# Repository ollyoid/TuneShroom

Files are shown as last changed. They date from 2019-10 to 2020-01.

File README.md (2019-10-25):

# 🎵🍄 TuneShroom
An artistic capacitive MIDI USB controller - Just a small project to practice artistic PCB design and embedded programming. Find out more on my [website](https://oliverchild.com/tuneshroom)

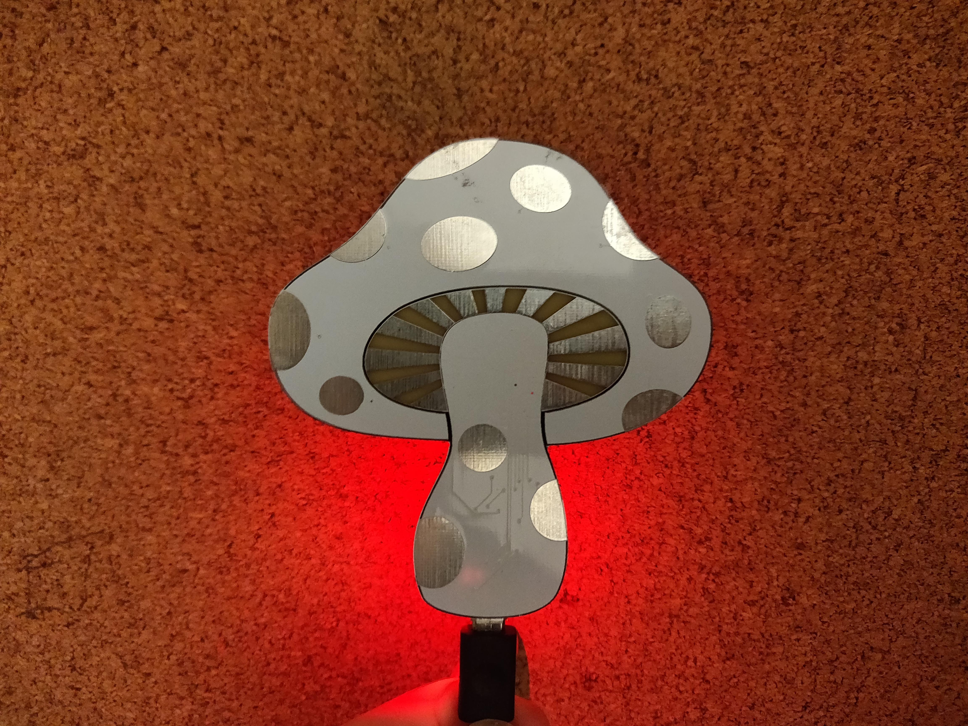
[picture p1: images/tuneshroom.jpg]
tuneshroom


## Hardware
The PCB was designed in KiCAD using the wonderful [svg2shenzhen](https://github.com/badgeek/svg2shenzhen) plugin for Inkscape. The circuit is essentially a [Sparkfun Pro Micro](https://www.sparkfun.com/products/12640), thanks Sparkfun for sharing the schematic! It uses an Atmega32u4 with native USB. Each of the IO pins is hooked directly to one of the touch pads on the front and acts as MIDI key.

## Firmware
I started out using Arduino but to access more pins and have more control I decided to go the bare metal approach. The current firmware is a patched version of [LUFA](https://github.com/abcminiuser/lufa) which does all the USB stuff for me. 

## Programming

To compile the firmware go into the [project folder](lufa/Projects/Tuneshroom/) and `make all`.

To Flash it onto the board you need an AVR programmer of some kind and to build a little ISP programmer with some pogo pins.

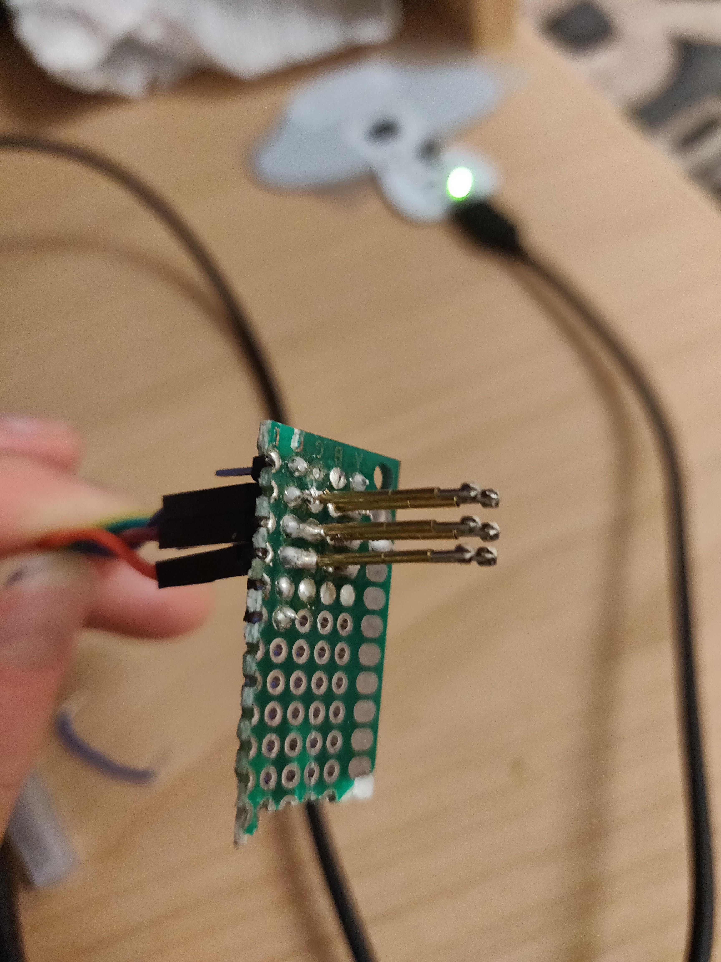
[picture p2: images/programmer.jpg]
programmer


Some fuses have to be changed from their default using:

```avrdude -c usbasp -p ATmega32u4 -U hfuse:w:0xD8:m -U lfuse:w:0xFF:m -U efuse:w:0xCB:```

Then it's just a case of programming it with:

```avrdude -c usbasp -p ATmega32u4 -U flash:w:TuneShroom.hex```

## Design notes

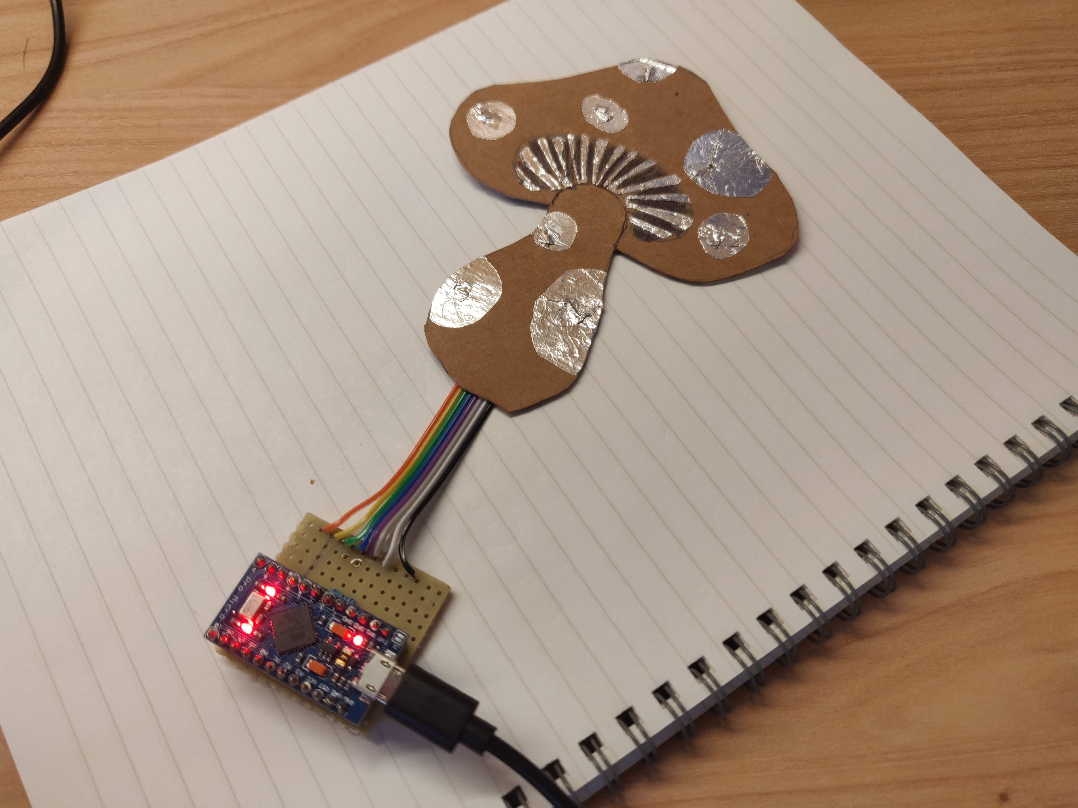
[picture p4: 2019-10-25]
images/prototype.jpg

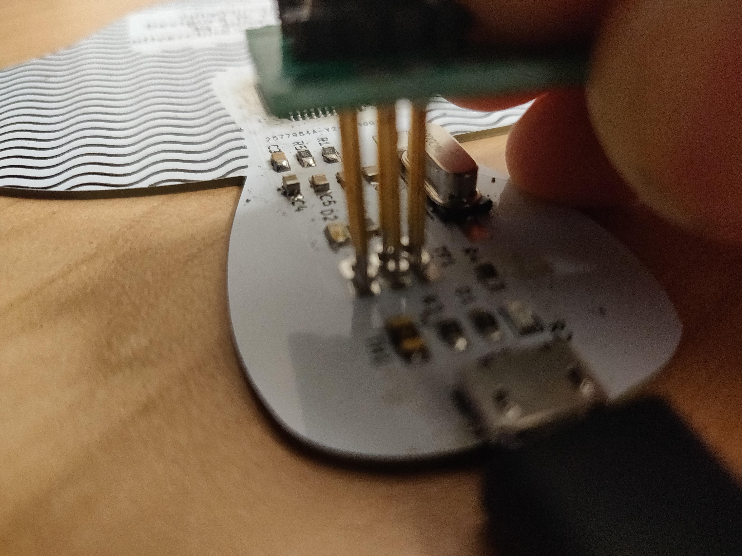
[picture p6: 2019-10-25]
images/programming.jpg

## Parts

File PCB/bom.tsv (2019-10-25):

References | Qty | Description
C1, C2 | 2 | C 22pF Unpolarized capacitor 0805 2012Metric Pad1.15x1.40mm HandSolder
C3, C5 | 2 | C 0.1uF Unpolarized capacitor 0805 2012Metric Pad1.15x1.40mm HandSolder
C4 | 1 | C 1uF Unpolarized capacitor 0805 2012Metric Pad1.15x1.40mm HandSolder
D1, D2 | 2 | LED Light emitting diode 0805 2012Metric Pad1.15x1.40mm HandSolder
J5, J7, J9, J11, J13, J15, J17, J19, J21, J1, J3, J4, J6, J8, J10, J12, J14, J16, J18, J20, J2, J22, J24, J25 | 24 | Conn 01x01 Generic connector, single row, 01x01, script generated (kicad-library-utils/schlib/autogen/connector/) contact
J23 | 1 | USB B Micro Type connector Micro-B Molex 47346-0001
R1, R5 | 2 | R 10K Resistor 0805 2012Metric Pad1.15x1.40mm HandSolder
R2, R3 | 2 | R 22 Resistor 0805 2012Metric Pad1.15x1.40mm HandSolder
R4, R6 | 2 | R 330 Resistor 0805 2012Metric Pad1.15x1.40mm HandSolder
TH1 | 1 | Thermistor Temperature dependent resistor Fuse 1206 3216Metric Pad1.42x1.75mm HandSolder
TP1 | 1 | ICSP
U1 | 1 | ATmega32U4-AU 16MHz, 16kB Flash, 1.25kB SRAM, 512B EEPROM, USB 2.0, TQFP-44 10x10mm P0.8mm
Y1 | 1 | Crystal 16MHz Two pin crystal SMD HC49-SD HandSoldering

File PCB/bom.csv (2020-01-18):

References | Qty | Description | Manufacturer | MPN | Manufacturer | MPN | Manufacturer | MPN | Digikey | Mouser | RS | Newark | Farnell
C1, C2 | 2 | C 22pF 0805 | KEMET | C0805C220J5GACTU | AVX | 08051A220J4T2A |  |  | 399-1113-1-ND | 80C0805C220J5G | 2644258P |  | 1625484
C3, C5 | 2 | C 0.1uF 0805 | Yageo | CC0805KRX7R9BB104 | Murata | GRM21BR71H104KA01L |  |  | 311-1140-6-ND | 603CC805KRX7R9BB104 | 6698842 |  | 3019949
C4 | 1 | C 1uF 0805 | TDK | C2012X7S2A105K125AB | Yageo | CC0805KKX7R8BB105 |  |  | 311-1456-6-ND | 603CC805KKX7R8BB105 | 7883054P |  | 1458903
D1, D2 | 2 | LED 0805 red | Broadcom | HSMS-C170 | VCC | 7012X1 |  |  | 516-1429-6-ND | 630HSMSC170 | 1371306 |  | 5790839
J23 | 1 | USB B Micro Type connector Micro-B Molex 47346-0001 |  | 47346-0001 | Molex | 47346-0001 |  |  | WM17141CT-ND | 538473460001 | 7025475 |  | 1568026
R1, R5 | 2 | R 10K 0805 | Vishay | CRCW080510K0FKEA | Panasonic | ERJ-6ENF1002V | Yageo | RC0805FR-0710KL | 311-10.0KCRDKR-ND | 603RC0805FR0710KL | 6790816 |  | 2148862
R2, R3 | 2 | R 22 0805 | Panasonic | ERJ-6GEYJ220V | Yageo | RC0805JR-0722RL |  |  | 311-22ARCT-ND | 603RC0805JR0722RL | 7326602 |  | 1799493
R4, R6 | 2 | R 330 0805 | Yageo | RC0805FR-07330RL | TE Connectivity | CPF0805B330RE1 |  |  | 311-330CRCT-ND | 603RC0805FR07330RL | 6183195 |  | 9237429
TH1 | 1 | F 1206 0.5A | Bel Fuse | 0ZCJ0050FF2G | Littelfuse | 1206L050YR |  |  | 507-1802-1-ND | 5300ZCJ0050FF2G | 7874198 |  | 2848530
U1 | 1 | ATmega32U4-AU | Microchip | ATMEGA32U4-AUR | Microchip | ATMEGA32U4-AU |  |  | ATMEGA32U4-AURDKR-ND | 556ATMEGA32U4AUR | 1310289 |  | 1748525
Y1 | 1 | Y 16M HC49 | Abracon | ABLS-16.000MHZ-B4-T |  |  |  |  | 535-10226-1-ND | 815ABLS16.0MT | 1710560 |  | 2467721

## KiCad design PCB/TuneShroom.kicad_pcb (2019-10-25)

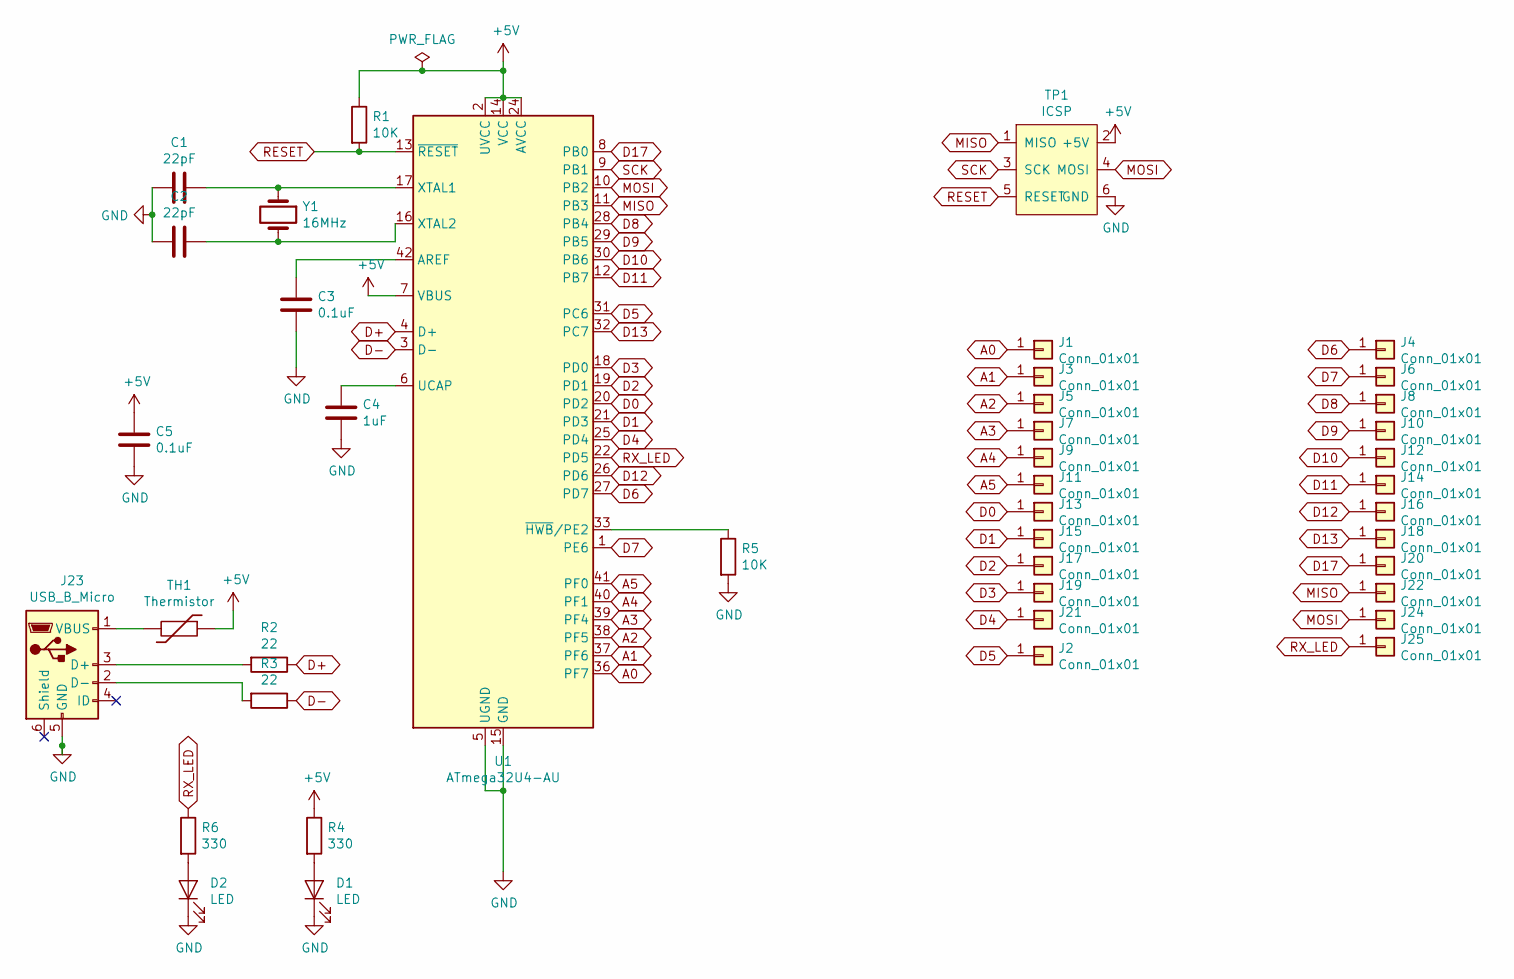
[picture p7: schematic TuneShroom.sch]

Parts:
C1, C2: 22pF; C_0805_2012Metric_Pad1.15x1.40mm_HandSolder
C3, C5: 0.1uF; C_0805_2012Metric_Pad1.15x1.40mm_HandSolder
C4: 1uF; C_0805_2012Metric_Pad1.15x1.40mm_HandSolder
D1, D2: LED; LED_0805_2012Metric_Pad1.15x1.40mm_HandSolder
J1, J2, J3, J4, J5, J6, J7, J8, J9, J10, J11, J12, J13, J14, J15, J16, J17, J18, J19, J20, J21, J22, J24, J25: Conn_01x01; contact
J23: USB_B_Micro; USB_Micro-B_Molex_47346-0001
R1, R5: 10K; R_0805_2012Metric_Pad1.15x1.40mm_HandSolder
R2, R3: 22; R_0805_2012Metric_Pad1.15x1.40mm_HandSolder
R4, R6: 330; R_0805_2012Metric_Pad1.15x1.40mm_HandSolder
TH1: Thermistor; Fuse_1206_3216Metric_Pad1.42x1.75mm_HandSolder
TP1: ICSP
U1: ATmega32U4-AU; TQFP-44_10x10mm_P0.8mm
Y1: 16MHz; Crystal_SMD_HC49-SD_HandSoldering

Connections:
+5V: C5.1, R1.1, R4.1, TH1.1, TP1.2 (+5V), U1.2 (UVCC), U1.7 (VBUS), U1.14 (VCC), U1.24 (AVCC), U1.34 (VCC), U1.44 (AVCC)
A0: J1.1, U1.36 (PF7)
A1: J3.1, U1.37 (PF6)
A2: J5.1, U1.38 (PF5)
A3: J7.1, U1.39 (PF4)
A4: J9.1, U1.40 (PF1)
A5: J11.1, U1.41 (PF0)
D0: J13.1, U1.20 (PD2)
D1: J15.1, U1.21 (PD3)
D2: J17.1, U1.19 (PD1)
D3: J19.1, U1.18 (PD0)
D4: J21.1, U1.25 (PD4)
D5: J2.1, U1.31 (PC6)
D6: J4.1, U1.27 (PD7)
D7: J6.1, U1.1 (PE6)
D8: J8.1, U1.28 (PB4)
D9: J10.1, U1.29 (PB5)
D10: J12.1, U1.30 (PB6)
D11: J14.1, U1.12 (PB7)
D12: J16.1, U1.26 (PD6)
D13: J18.1, U1.32 (PC7)
D17: J20.1, U1.8 (PB0)
D+: R2.1, U1.4 (D+)
D-: R3.1, U1.3 (D-)
GND: C1.2, C2.2, C3.2, C4.2, C5.2, D1.1 (K), D2.1 (K), J23.5 (GND), R5.2, TP1.6 (GND), U1.5 (UGND), U1.15 (GND), U1.23 (GND), U1.35 (GND), U1.43 (GND)
MISO: J22.1, TP1.1 (MISO), U1.11 (PB3)
MOSI: J24.1, TP1.4 (MOSI), U1.10 (PB2)
unnamed: C1.1, U1.17 (XTAL1), Y1.1
unnamed: C2.1, U1.16 (XTAL2), Y1.2
unnamed: C3.1, U1.42 (AREF)
unnamed: C4.1, U1.6 (UCAP)
unnamed: D1.2 (A), R4.2
unnamed: D2.2 (A), R6.2
unnamed: J23.1 (VBUS), TH1.2
unnamed: J23.2 (D-), R3.2
unnamed: J23.3 (D+), R2.2
unnamed: R5.1, U1.33 (~HWB~/PE2)
RESET: R1.2, TP1.5 (RESET), U1.13 (~RESET)
RX_LED: J25.1, R6.1, U1.22 (PD5)
SCK: TP1.3 (SCK), U1.9 (PB1)

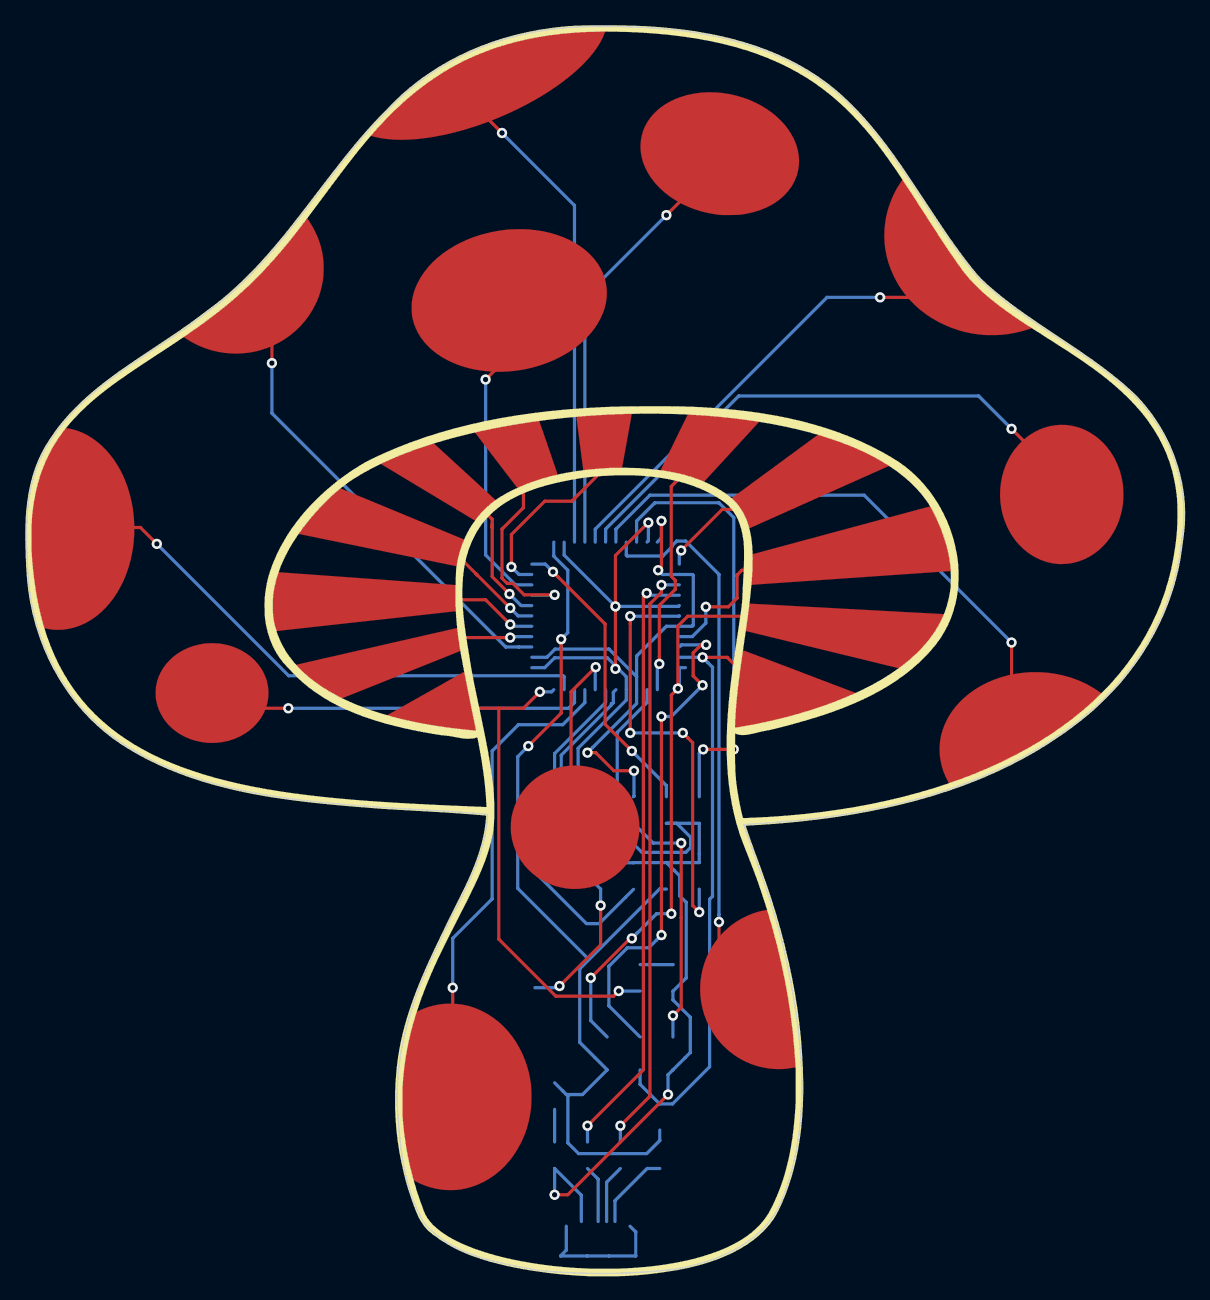
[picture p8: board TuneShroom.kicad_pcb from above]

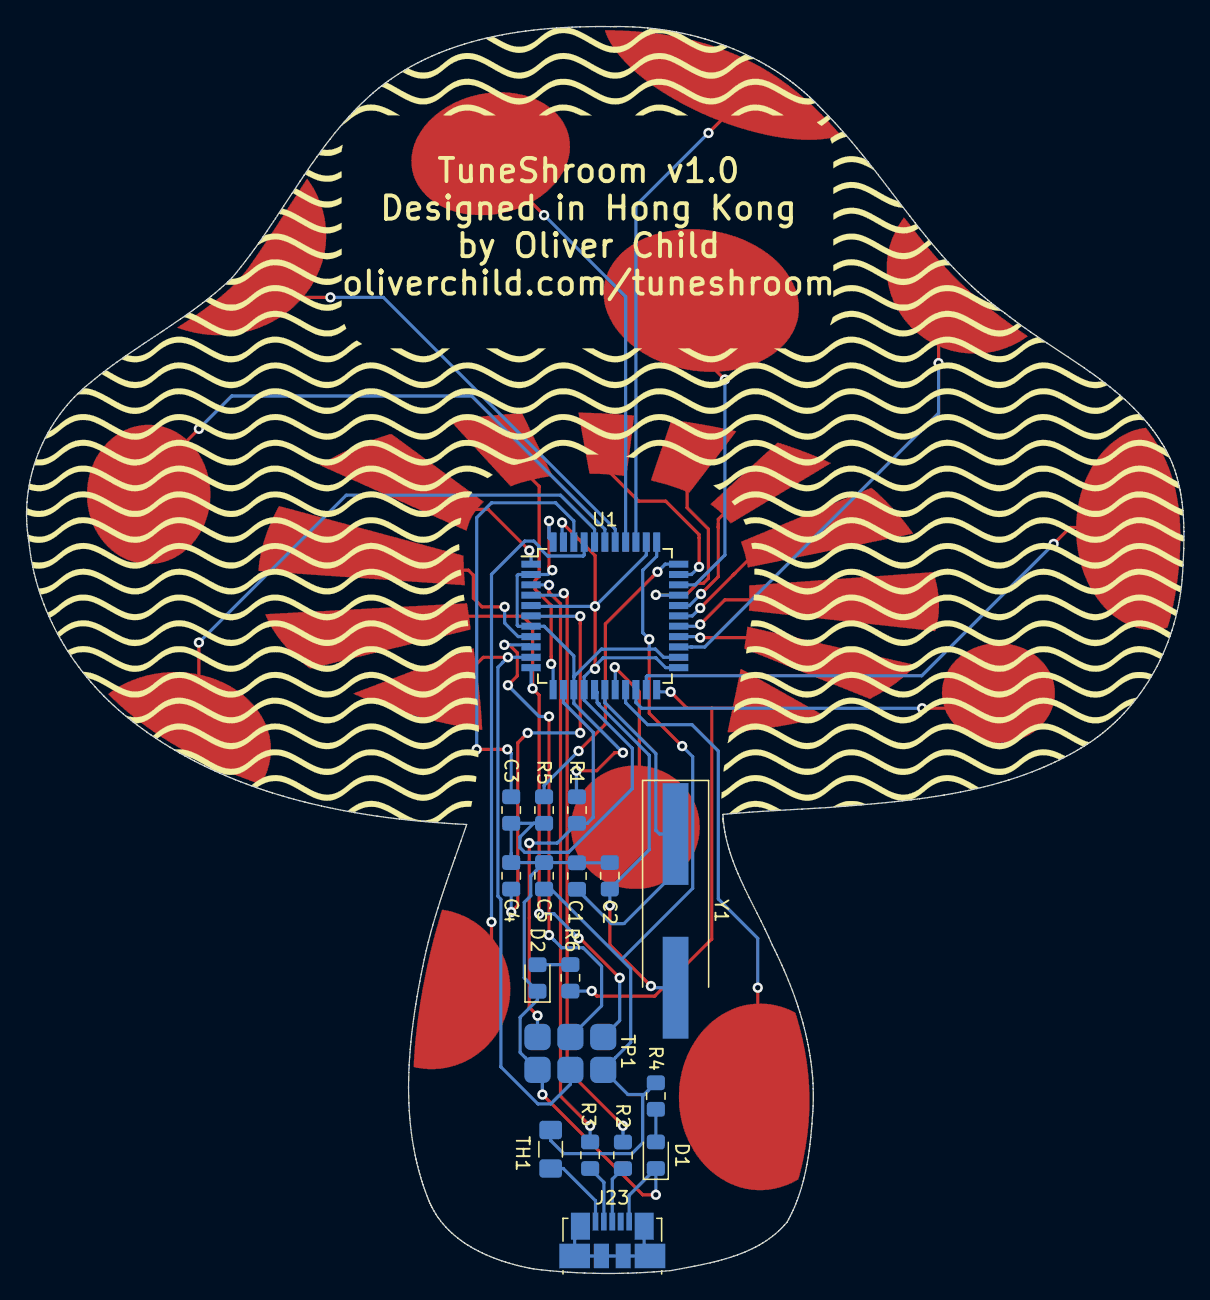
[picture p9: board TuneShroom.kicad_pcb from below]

Board: 2 copper layers, 89.4 x 96.3 mm, 42 parts (18 on the bottom side), 40 nets.

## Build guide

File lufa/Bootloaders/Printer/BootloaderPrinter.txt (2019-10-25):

/** \file
 *
 *  This file contains special DoxyGen information for the generation of the main page and other special
 *  documentation pages. It is not a project source file.
 */

/** \mainpage Printer Class USB AVR Bootloader
 *
 *  \section Sec_Compat Demo Compatibility:
 *
 *  The following list indicates what microcontrollers are compatible with this demo.
 *
 *  \li Series 7 USB AVRs (AT90USBxxx7)
 *  \li Series 6 USB AVRs (AT90USBxxx6)
 *  \li Series 4 USB AVRs (ATMEGAxxU4)
 *  \li Series 2 USB AVRs (AT90USBxx2, ATMEGAxxU2)
 *
 *  \section Sec_Info USB Information:
 *
 *  The following table gives a rundown of the USB utilization of this demo.
 *
 *  <table>
 *   <tr>
 *    <td><b>USB Mode:</b></td>
 *    <td>Device</td>
 *   </tr>
 *   <tr>
 *    <td><b>USB Class:</b></td>
 *    <td>Printer Class</td>
 *   </tr>
 *   <tr>
 *    <td><b>USB Subclass:</b></td>
 *    <td>Printer Subclass</td>
 *   </tr>
 *   <tr>
 *    <td><b>Relevant Standards:</b></td>
 *    <td>USBIF Printer Class Standard</td>
 *   </tr>
 *   <tr>
 *    <td><b>Supported USB Speeds:</b></td>
 *    <td>Full Speed Mode</td>
 *   </tr>
 *  </table>
 *
 *  \section Sec_Description Project Description:
 *
 *  This bootloader enumerates to the host as a Generic Text Only Printer device, capable of reading and parsing
 *  "printed" plain-text Intel HEX files to load firmware onto the AVR.
 *
 *  Out of the box this bootloader builds for the AT90USB1287 with an 8KB bootloader section size, and will fit
 *  into 4KB of bootloader space. If you wish to alter this size and/or change the AVR model, you will need to
 *  edit the MCU, FLASH_SIZE_KB and BOOT_SECTION_SIZE_KB values in the accompanying makefile.
 *
 *  When the bootloader is running, the board's LED(s) will flash at regular intervals to distinguish the
 *  bootloader from the normal user application.
 *
 *  \section Sec_Running Running the Bootloader
 *
 *  On the USB AVR8 devices, setting the \c HWBE device fuse will cause the bootloader to run if the \c HWB pin of
 *  the AVR is grounded when the device is reset.
 *
 *  The are two behaviours of this bootloader, depending on the device's fuses:
 *
 *  <b>If the device's BOOTRST fuse is set</b>, the bootloader will run any time the system is reset from
 *  the external reset pin, unless no valid user application has been loaded. To initiate the bootloader, the
 *  device's external reset pin should be grounded momentarily.
 *
 *  <b>If the device's BOOTRST fuse is not set</b>, the bootloader will run only if initiated via a software
 *  jump, or if the \c HWB pin was low during the last device reset (if the \c HWBE fuse is set).
 *
 *  For board specific exceptions to the above, see below.
 *
 *  \subsection SSec_XPLAIN Atmel Xplain Board
 *  Ground the USB AVR JTAG's \c TCK pin to ground when powering on the board to start the bootloader. This assumes the
 *  \c HWBE fuse is cleared and the \c BOOTRST fuse is set as the HWBE pin is not user accessible on this board.
 *
 *  \subsection SSec_Leonardo Arduino Leonardo Board
 *  Ground \c IO13 when powering the board to start the bootloader. This assumes the \c HWBE fuse is cleared and the
 *  \c BOOTRST fuse is set as the HWBE pin is not user accessible on this board.
 *
 *  \section Sec_Installation Driver Installation
 *
 *  This bootloader uses the Generic Text-Only printer drivers inbuilt into all modern operating systems, thus no
 *  additional drivers need to be supplied for correct operation.
 *
 *  \section Sec_HostApp Host Controller Application
 *
 *  This bootloader is compatible with Notepad under Windows, and the command line \c lpr utility under Linux.
 *
 *  \subsection SSec_Notepad Notepad (Windows)
 *
 *  While most text applications under Windows will be compatible with the bootloader, the inbuilt Notepad utility
 *  is recommended as it will introduce minimal formatting changes to the output stream. To program with Notepad,
 *  open the target HEX file and print it to the Generic Text Only printer device the bootloader creates.
 *
 *  \subsection SSec_LPR LPR (Linux)
 *
 *  While the CUPS framework under Linux will enumerate the bootloader as a Generic Text-Only printer, many
 *  applications will refuse to print to the device due to the lack of rich formatting options available. As a result,
 *  under Linux HEX files must be printed via the low level \c lpr utility instead.
 *
 *  \code
 *  cat Mouse.hex | lpr
 *  \endcode
 *
 *  \section Sec_API User Application API
 *
 *  Several user application functions for FLASH and other special memory area manipulations are exposed by the bootloader,
 *  allowing the user application to call into the bootloader at runtime to read and write FLASH data.
 *
 *  By default, the bootloader API jump table is located 32 bytes from the end of the device's FLASH memory, and follows the
 *  following layout:
 *
 *  \code
 *  #define BOOTLOADER_API_TABLE_SIZE          32
 *  #define BOOTLOADER_API_TABLE_START         ((FLASHEND + 1UL) - BOOTLOADER_API_TABLE_SIZE)
 *  #define BOOTLOADER_API_CALL(Index)         (void*)((BOOTLOADER_API_TABLE_START + (Index * 2)) / 2)
 *
 *  void    (*BootloaderAPI_ErasePage)(uint32_t Address)               = BOOTLOADER_API_CALL(0);
 *  void    (*BootloaderAPI_WritePage)(uint32_t Address)               = BOOTLOADER_API_CALL(1);
 *  void    (*BootloaderAPI_FillWord)(uint32_t Address, uint16_t Word) = BOOTLOADER_API_CALL(2);
 *  uint8_t (*BootloaderAPI_ReadSignature)(uint16_t Address)           = BOOTLOADER_API_CALL(3);
 *  uint8_t (*BootloaderAPI_ReadFuse)(uint16_t Address)                = BOOTLOADER_API_CALL(4);
 *  uint8_t (*BootloaderAPI_ReadLock)(void)                            = BOOTLOADER_API_CALL(5);
 *  void    (*BootloaderAPI_WriteLock)(uint8_t LockBits)               = BOOTLOADER_API_CALL(6);
 *
 *  #define BOOTLOADER_MAGIC_SIGNATURE_START   (BOOTLOADER_API_TABLE_START + (BOOTLOADER_API_TABLE_SIZE - 2))
 *  #define BOOTLOADER_MAGIC_SIGNATURE         0xDCFB
 *
 *  #define BOOTLOADER_CLASS_SIGNATURE_START   (BOOTLOADER_API_TABLE_START + (BOOTLOADER_API_TABLE_SIZE - 4))
 *  #define BOOTLOADER_PRINTER_SIGNATURE       0xDF20
 *
 *  #define BOOTLOADER_ADDRESS_START           (BOOTLOADER_API_TABLE_START + (BOOTLOADER_API_TABLE_SIZE - 8))
 *  #define BOOTLOADER_ADDRESS_LENGTH          4
 *  \endcode
 *
 *  From the application the API support of the bootloader can be detected by reading the FLASH memory bytes located at address
 *  \c BOOTLOADER_MAGIC_SIGNATURE_START and comparing them to the value \c BOOTLOADER_MAGIC_SIGNATURE. The class of bootloader
 *  can be determined by reading the FLASH memory bytes located at address \c BOOTLOADER_CLASS_SIGNATURE_START and comparing them
 *  to the value \c BOOTLOADER_PRINTER_SIGNATURE. The start address of the bootloader can be retrieved by reading the bytes of FLASH
 *  memory starting from address \c BOOTLOADER_ADDRESS_START.
 *
 *  \subsection SSec_API_MemLayout Device Memory Map
 *  The following illustration indicates the final memory map of the device when loaded with the bootloader.
 *
 *  \verbatim
 *  +----------------------------+ 0x0000
 *  |                            |
 *  |                            |
 *  |                            |
 *  |                            |
 *  |                            |
 *  |                            |
 *  |                            |
 *  |                            |
 *  |      User Application      |
 *  |                            |
 *  |                            |
 *  |                            |
 *  |                            |
 *  |                            |
 *  |                            |
 *  |                            |
 *  +----------------------------+ FLASHEND - BOOT_SECTION_SIZE
 *  |                            |
 *  |   Bootloader Application   |
 *  | (Not User App. Accessible) |
 *  |                            |
 *  +----------------------------+ FLASHEND - 96
 *  |   API Table Trampolines    |
 *  | (Not User App. Accessible) |
 *  +----------------------------+ FLASHEND - 32
 *  |    Bootloader API Table    |
 *  |   (User App. Accessible)   |
 *  +----------------------------+ FLASHEND - 8
 *  |   Bootloader ID Constants  |
 *  |   (User App. Accessible)   |
 *  +----------------------------+ FLASHEND
 *  \endverbatim
 *
 *
 *  \section Sec_KnownIssues Known Issues:
 *
 *  \par On Linux machines, new firmware fails to be sent to the device via CUPS.
 *  Only a limited subset of normal printer functionality is exposed via the
 *  bootloader, causing CUPS to reject print requests from applications that
 *  are unable to handle true plain-text printing. For best results, the low
 *  level \c lpr command should be used to print new firmware to the bootloader.
 *
 *  \section Sec_Options Project Options
 *
 *  The following defines can be found in this demo, which can control the demo behaviour when defined, or changed in value.
 *
 *  <table>
 *   <tr>
 *    <td>
 *     None
 *    </td>
 *   </tr>
 *  </table>
 */

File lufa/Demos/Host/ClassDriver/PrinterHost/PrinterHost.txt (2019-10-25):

/** \file
 *
 *  This file contains special DoxyGen information for the generation of the main page and other special
 *  documentation pages. It is not a project source file.
 */

/** \mainpage Printer Host Demo
 *
 *  \section Sec_Compat Demo Compatibility:
 *
 *  The following list indicates what microcontrollers are compatible with this demo.
 *
 *  \li Series 7 USB AVRs (AT90USBxxx7)
 *
 *  \section Sec_Info USB Information:
 *
 *  The following table gives a rundown of the USB utilization of this demo.
 *
 *  <table>
 *   <tr>
 *    <td><b>USB Mode:</b></td>
 *    <td>Host</td>
 *   </tr>
 *   <tr>
 *    <td><b>USB Class:</b></td>
 *    <td>Printer Device</td>
 *   </tr>
 *   <tr>
 *    <td><b>USB Subclass:</b></td>
 *    <td>Bidirectional Protocol</td>
 *   </tr>
 *   <tr>
 *    <td><b>Relevant Standards:</b></td>
 *    <td>USBIF Printer Class Specification \n
 *        PCL Language Specification</td>
 *   </tr>
 *   <tr>
 *    <td><b>Supported USB Speeds:</b></td>
 *    <td>Low Speed Mode \n
 *        Full Speed Mode</td>
 *   </tr>
 *  </table>
 *
 *  \section Sec_Description Project Description:
 *
 *  Printer host demonstration application. This gives a simple reference
 *  application for implementing a USB Printer host, for USB printers using
 *  the bidirectional data encapsulation protocol and PCL language.
 *
 *  Upon connection of a compatible printer, the printer's device ID is sent
 *  to the AVR's serial port, and a simple test page is printed using the PCL
 *  printer language.
 *
 *  \section Sec_Options Project Options
 *
 *  The following defines can be found in this demo, which can control the demo behaviour when defined, or changed in value.
 *
 *  <table>
 *   <tr>
 *    <td>
 *     None
 *    </td>
 *   </tr>
 *  </table>
 */

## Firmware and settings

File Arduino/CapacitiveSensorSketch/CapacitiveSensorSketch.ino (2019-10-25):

#include <CapacitiveSensor.h>
#include "MIDIUSB.h"

/*
 * CapitiveSense Library Demo Sketch
 * Paul Badger 2008
 * Uses a high value resistor e.g. 10M between send pin and receive pin
 * Resistor effects sensitivity, experiment with values, 50K - 50M. Larger resistor values yield larger sensor values.
 * Receive pin is the sensor pin - try different amounts of foil/metal on this pin
 */

 // readCapacitivePin
//  Input: Arduino pin number
//  Output: A number, from 0 to 17 expressing
//  how much capacitance is on the pin
//  When you touch the pin, or whatever you have
//  attached to it, the number will get higher

uint8_t readCapacitivePin(int pinToMeasure) {
  // Variables used to translate from Arduino to AVR pin naming
  volatile uint8_t* port;
  volatile uint8_t* ddr;
  volatile uint8_t* pin;
  // Here we translate the input pin number from
  //  Arduino pin number to the AVR PORT, PIN, DDR,
  //  and which bit of those registers we care about.
  byte bitmask;
  port = portOutputRegister(digitalPinToPort(pinToMeasure));
  ddr = portModeRegister(digitalPinToPort(pinToMeasure));
  bitmask = digitalPinToBitMask(pinToMeasure);
  pin = portInputRegister(digitalPinToPort(pinToMeasure));
  // Discharge the pin first by setting it low and output
  *port &= ~(bitmask);
  *ddr  |= bitmask;
  delay(1);
  uint8_t SREG_old = SREG; //back up the AVR Status Register
  // Prevent the timer IRQ from disturbing our measurement
  noInterrupts();
  // Make the pin an input with the internal pull-up on
  *ddr &= ~(bitmask);
  *port |= bitmask;
  // Now see how long the pin to get pulled up. This manual unrolling of the loop
  // decreases the number of hardware cycles between each read of the pin,
  // thus increasing sensitivity.
  uint8_t cycles = 17;
  if (*pin & bitmask) { cycles =  0;}
  else if (*pin & bitmask) { cycles =  1;}
  else if (*pin & bitmask) { cycles =  2;}
  else if (*pin & bitmask) { cycles =  3;}
  else if (*pin & bitmask) { cycles =  4;}
  else if (*pin & bitmask) { cycles =  5;}
  else if (*pin & bitmask) { cycles =  6;}
  else if (*pin & bitmask) { cycles =  7;}
  else if (*pin & bitmask) { cycles =  8;}
  else if (*pin & bitmask) { cycles =  9;}
  else if (*pin & bitmask) { cycles = 10;}
  else if (*pin & bitmask) { cycles = 11;}
  else if (*pin & bitmask) { cycles = 12;}
  else if (*pin & bitmask) { cycles = 13;}
  else if (*pin & bitmask) { cycles = 14;}
  else if (*pin & bitmask) { cycles = 15;}
  else if (*pin & bitmask) { cycles = 16;}

  // End of timing-critical section; turn interrupts back on if they were on before, or leave them off if they were off before

  SREG = SREG_old;
  
  // Discharge the pin again by setting it low and output
  //  It's important to leave the pins low if you want to 
  //  be able to touch more than 1 sensor at a time - if
  //  the sensor is left pulled high, when you touch
  //  two sensors, your body will transfer the charge between
  //  sensors.

  *port &= ~(bitmask);
  *ddr  |= bitmask;
  
  return cycles;
}

int pins[] = {0,2,3,4,5,6,7,8};
long totals[8];
int noteState[8] = {0}; 
int notes[] = {40, 42, 44, 45, 47, 49, 51, 52};

void setup()                    
{
   Serial.begin(9600);
}

void noteOn(byte channel, byte pitch, byte velocity) {
  midiEventPacket_t noteOn = {0x09, 0x90 | channel, pitch, velocity};
  MidiUSB.sendMIDI(noteOn);
}

void noteOff(byte channel, byte pitch, byte velocity) {
  midiEventPacket_t noteOff = {0x08, 0x80 | channel, pitch, velocity};
  MidiUSB.sendMIDI(noteOff);
}

void loop()                    
{
    
    for(int i = 0; i < 8; i++){
      int noteVal = readCapacitivePin(pins[i]);
      if(noteVal > 1){
        noteState[i] = 1;
        noteOn(0, notes[i], 64);
      }
      else if(noteState[i]){
        noteState[i] = 0;
        noteOff(0, notes[i], 64);
        Serial.print("!!!");
      }
      Serial.print(totals[i]);                  // print sensor output 1
      Serial.print("\t");
    }
    Serial.print("\n");
    MidiUSB.flush();
}

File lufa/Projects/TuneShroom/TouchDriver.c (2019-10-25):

#include "TouchDriver.h"

/* Original code by Mario Becker, Fraunhofer IGD, 2007
    Thank you <3 for making it open source
*/
uint8_t readTouch(TouchPad *pad)
{
    volatile uint8_t *pin  = pad->pin;
    volatile uint8_t *port = pad->port;
    volatile uint8_t *ddr  = pad->ddr;

    uint8_t bitmask = pad->bitmask;

    /* Discharge pin*/
    *port &= ~(bitmask);
    *ddr  |= bitmask;
    Delay_MS(1);

    /* Save the status register */
    uint8_t MCUSR_old = MCUSR; // Not sure Why we need this?
    /* Turn off interrupts */
    GlobalInterruptDisable();
    /* Charge pin*/
    uint8_t cycles = 17;
    /* Make the pin an input with the internal pull-up on*/
    *ddr &= ~(bitmask);
    *port |= bitmask;
    /* Now see how long the pin to get pulled up. This manual unrolling of the loop
     decreases the number of hardware cycles between each read of the pin,
     thus increasing sensitivity. */
    if (*pin & bitmask) { cycles =  0;}
    else if (*pin & bitmask) { cycles =  1;}
    else if (*pin & bitmask) { cycles =  2;}
    else if (*pin & bitmask) { cycles =  3;}
    else if (*pin & bitmask) { cycles =  4;}
    else if (*pin & bitmask) { cycles =  5;}
    else if (*pin & bitmask) { cycles =  6;}
    else if (*pin & bitmask) { cycles =  7;}
    else if (*pin & bitmask) { cycles =  8;}
    else if (*pin & bitmask) { cycles =  9;}
    else if (*pin & bitmask) { cycles = 10;}
    else if (*pin & bitmask) { cycles = 11;}
    else if (*pin & bitmask) { cycles = 12;}
    else if (*pin & bitmask) { cycles = 13;}
    else if (*pin & bitmask) { cycles = 14;}
    else if (*pin & bitmask) { cycles = 15;}
    else if (*pin & bitmask) { cycles = 16;}

    /* Turn back on interrupts */
    GlobalInterruptEnable();
    MCUSR = MCUSR_old;

    /* Discharge pins again*/
    *port &= ~(bitmask);
    *ddr  |= bitmask;

    return(cycles);
}


/* Define touch pads as global struct here.
QUESTION: Is this the best way to do it? Funcitons and dynamic memory allocation?
Should I instead use a Macro function for this? This isn't very easy to change when I
come up wth a new board layout*/

/* On v1.0 of the board these are in the order of outer clockwise, then inner clockwise,
 starting fron the USB port.
*/

extern TouchPad touch1 =
	{
		.pin =  &PINF,
		.port = &PORTF,
		.ddr = &DDRF,
		.bitmask = 1 << 0,
        .state = 0,
	};

extern TouchPad touch2 =
	{
		.pin =  &PINF,
		.port = &PORTF,
		.ddr = &DDRF,
		.bitmask = 1 << 1,
        .state = 0,
	};

extern TouchPad touch3 =
	{
		.pin =  &PINF,
		.port = &PORTF,
		.ddr = &DDRF,
		.bitmask = 1 << 4,
        .state = 0,
	};

extern TouchPad touch4 =
	{
		.pin =  &PINF,
		.port = &PORTF,
		.ddr = &DDRF,
		.bitmask = 1 << 5,
        .state = 0,
	};

extern TouchPad touch5 =
	{
		.pin =  &PINF,
		.port = &PORTF,
		.ddr = &DDRF,
		.bitmask = 1 << 6,
        .state = 0,
	};

extern TouchPad touch6 =
	{
		.pin =  &PINF,
		.port = &PORTF,
		.ddr = &DDRF,
		.bitmask = 1 << 7,
        .state = 0,
	};

extern TouchPad touch7 =
	{
		.pin =  &PINC,
		.port = &PORTC,
		.ddr = &DDRC,
		.bitmask = 1 << 6,
        .state = 0,
	};

extern TouchPad touch8 =
	{
		.pin =  &PIND,
		.port = &PORTD,
		.ddr = &DDRD,
		.bitmask = 1 << 4,
        .state = 0,
	};

extern TouchPad touch9 =
	{
		.pin =  &PIND,
		.port = &PORTD,
		.ddr = &DDRD,
		.bitmask = 1 << 3,
        .state = 0,
	};

extern TouchPad touch10 =
	{
		.pin =  &PIND,
		.port = &PORTD,
		.ddr = &DDRD,
		.bitmask = 1 << 2,
        .state = 0,
	};

extern TouchPad touch11 =
	{
		.pin =  &PIND,
		.port = &PORTD,
		.ddr = &DDRD,
		.bitmask = 1 << 0,
        .state = 0,
	};

extern TouchPad touch12 =
	{
		.pin =  &PIND,
		.port = &PORTD,
		.ddr = &DDRD,
		.bitmask = 1 << 1,
        .state = 0,
	};

extern TouchPad touch13 =
	{
		.pin =  &PINB,
		.port = &PORTB,
		.ddr = &DDRB,
		.bitmask = 1 << 2,
        .state = 0,
	};

extern TouchPad touch14 =
	{
		.pin =  &PINB,
		.port = &PORTB,
		.ddr = &DDRB,
		.bitmask = 1 << 3,
        .state = 0,
    };

extern TouchPad touch15 =
	{
		.pin =  &PINB,
		.port = &PORTB,
		.ddr = &DDRB,
		.bitmask = 1 << 0,
        .state = 0,
	};

extern TouchPad touch16 =
	{
		.pin =  &PINE,
		.port = &PORTE,
		.ddr = &DDRE,
		.bitmask = 1 << 6,
        .state = 0,
	};

extern TouchPad touch17 =
	{
		.pin =  &PINB,
		.port = &PORTB,
		.ddr = &DDRB,
		.bitmask = 1 << 7,
        .state = 0,
	};

extern TouchPad touch18 =
	{
		.pin =  &PINC,
		.port = &PORTC,
		.ddr = &DDRC,
		.bitmask = 1 << 7,
        .state = 0,
	};

extern TouchPad touch19 =
	{
		.pin =  &PINB,
		.port = &PORTB,
		.ddr = &DDRB,
		.bitmask = 1 << 6,
        .state = 0,
	};

extern TouchPad touch20 =
	{
		.pin =  &PINB,
		.port = &PORTB,
		.ddr = &DDRB,
		.bitmask = 1 << 5,
        .state = 0,
	};

extern TouchPad touch21 =
	{
		.pin =  &PINB,
		.port = &PORTB,
		.ddr = &DDRB,
		.bitmask = 1 << 4,
        .state = 0,
	};

extern TouchPad touch22 =
	{
		.pin =  &PIND,
		.port = &PORTD,
		.ddr = &DDRD,
		.bitmask = 1 << 7,
        .state = 0,
	};

extern TouchPad touch23 =
	{
		.pin =  &PIND,
		.port = &PORTD,
		.ddr = &DDRD,
		.bitmask = 1 << 6,
        .state = 0,
	};

extern TouchPad touch24 =
	{
		.pin =  &PIND,
		.port = &PORTD,
		.ddr = &DDRD,
		.bitmask = 1 << 5,
        .state = 0,
	};

extern TouchPad* pads[24] = {&touch1, &touch2, &touch3, &touch4, &touch5, &touch6, &touch7, &touch8, &touch9, &touch10, &touch11, &touch12, &touch13, &touch14, &touch15, &touch16, &touch17, &touch18, &touch19, &touch20, &touch21, &touch22, &touch23, &touch24};

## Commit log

2019-10-25 fixed gitignmore
    [bom.tsv]
2020-01-18 new bom with part numbers
    [bom.csv]
